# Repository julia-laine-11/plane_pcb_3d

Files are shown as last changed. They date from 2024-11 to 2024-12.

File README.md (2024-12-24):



top view (smt leds & resistors and thru hole resistor holes)



side view (no electronics here)



I ordered them 12/8/24 and they were shipped 12/12/24

They arrived 12/23/24 (very fast!)



I began by adding all the thru hole components on the bottom side of the horizontal piece. The bottom LEDs face forward. Afterwards, I added the surface mount LEDs on the back. I forgot that I didn't have any green 0603s, so I (safely) stole some from a nearby battery pack that was no longer in use. Unfortunately, I lost all but 1 from the very windy reflow station at home. 

Honestly, that was okay though since I really only needed 1 for my dad. I figure I'll give the other 4 as random gifts to my aerospace friends or something.





I then tested it of course, because I desperately wanted to see it, and I was also super nervous I put the 0603 LEDs in backwards since they're so tiny.



(I did put the green LED in backwards once, but I flipped it around and it lit up)

To power it, I used CR2032 batteries with a small piece of tin spot welded onto each side




About now, I realized I forgot to add a switch. I had always intended to glue the battery on, but I'm not sure why I never thought of the switch. 

To power it on I attached small wires onto a potentiometer between the battery + and the PCB. After gluing both the battery and the pot on, I realized that was not going to work since the red SMT LED was always on. 

WhatsAppVideo2024-12-23at20 40 40-ezgif com-crop

I went and found a button and replaced the pot.





It isn't ideal or the prettiest, but it is hidden on the bottom :)

WhatsAppVideo2024-12-23at20 40 21-ezgif com-optimize (1)

I am happy with these results, but there's definitely room for improvement. If I manufacture these again I will definitely add a switch. I also might consider making the slits on each piece a tiny bit wider since there was some minor sanding I had to do. I am not sure if I would do this or not because the pieces fit so nicely after I gently tapped them together with a harder object.

I will also definitely increase the distance of the resistor holes. They were the right size and hold the resistors, but it was a little annoying to bend the wires nicely for them to fit. If the holes were slightly farther apart, they would fit so much better.

I did like how the + and - were on either side of the vertical piece. It made it easier to put the battery in place and not worry about covering up a port. It also let me place a button in and keep the wires relatively short. I would add a small hole or indent for the wire in the future though if I do keep the + on the opposite side. I can also just add a + and - to both sides so I can decide what to do depending on my materials. The school typically has everything I need, but if I am at home I might not have everything.

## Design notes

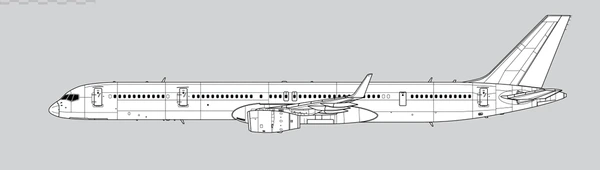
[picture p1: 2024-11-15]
pcb_shape/side reference.webp

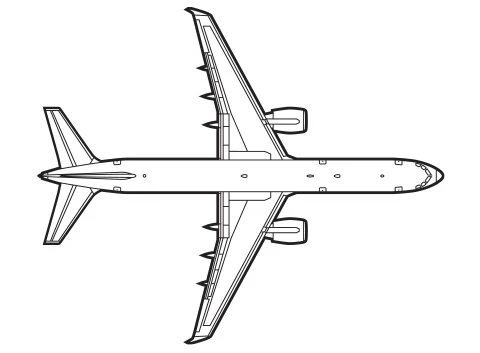
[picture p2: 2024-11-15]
pcb_shape/top reference.webp

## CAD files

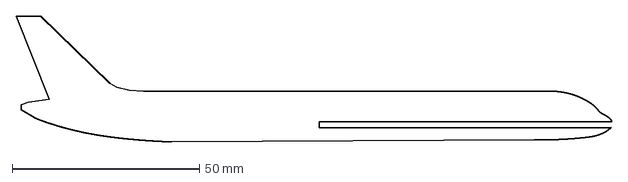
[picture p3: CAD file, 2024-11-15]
pcb_shape/plane side.dxf
159.0 x 33.6 mm

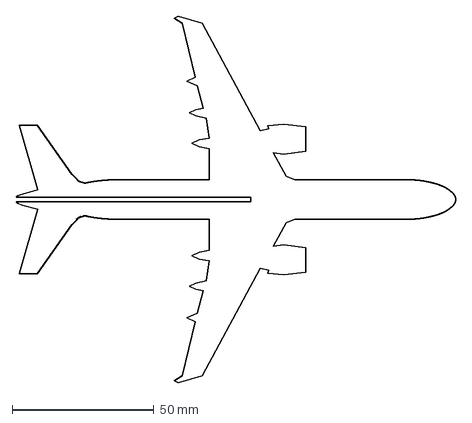
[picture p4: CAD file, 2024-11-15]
pcb_shape/plane top.dxf
155.1 x 129.4 mm

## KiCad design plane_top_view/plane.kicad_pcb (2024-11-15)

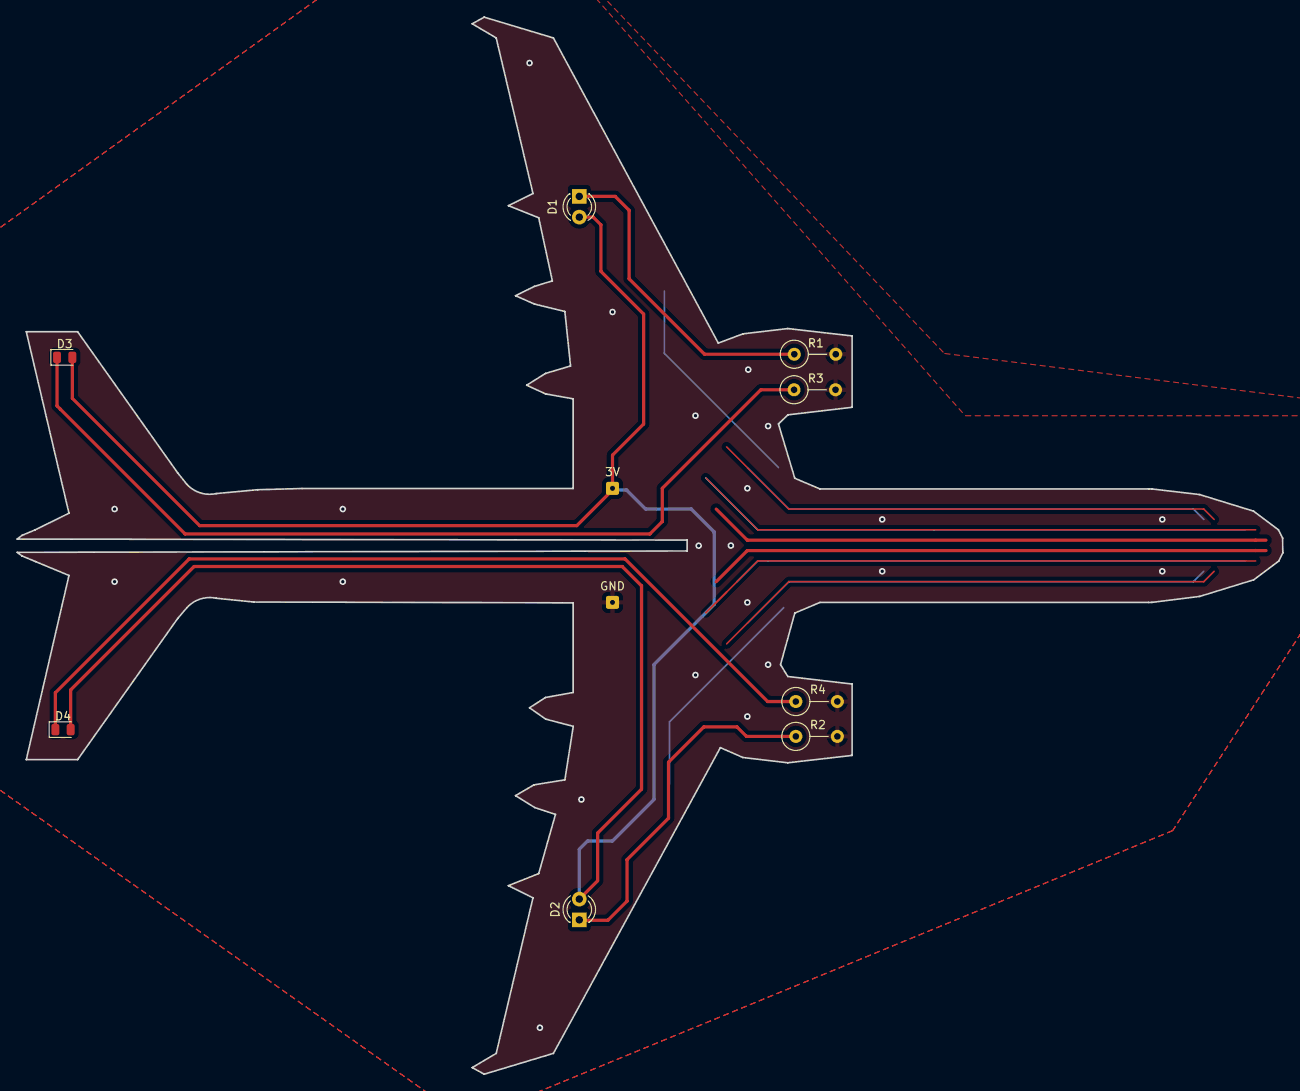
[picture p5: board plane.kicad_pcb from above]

Board: 2 copper layers, 155.0 x 129.4 mm, 10 parts (0 on the bottom side), 6 nets.

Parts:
3V: 3v; SolderWire-0.1sqmm_1x01_D0.4mm_OD1mm
D1, D2: TSAL4400; LED_D3.0mm_IRBlack
D3, D4: LED; LED_0805_2012Metric
GND: GND; SolderWire-0.1sqmm_1x01_D0.4mm_OD1mm
R1, R2, R3, R4: RC0201FR-0710KL; R_Axial_DIN0309_L9.0mm_D3.2mm_P5.08mm_Vertical

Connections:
+3V0: 3V.1, D1.2 (A), D2.2 (A), D3.2 (A), D4.2 (A)
GND: GND.1, R1.2, R2.2, R3.2, R4.2
unnamed: D1.1 (K), R1.1
unnamed: D2.1 (K), R2.1
unnamed: D3.1 (K), R3.1
unnamed: D4.1 (K), R4.1

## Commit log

2024-11-15 uploaded plane kicad project
    [plane-B_Cu.gbr, plane-B_Mask.gbr, plane-B_Paste.gbr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]
2024-11-15 organized into folders
    [plane side.dxf, plane top.dxf]
2024-11-15 changed folders
    [plane-B_Cu.gbr, plane-B_Mask.gbr, plane-B_Paste.gbr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]
2024-11-15 made it less jank
    [plane.kicad_pcb, plane.kicad_sch]
2024-11-15 made it actually have connected grounds
    [plane-B_Cu.gbl, plane-B_Mask.gbr, plane-B_Mask.gbs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]
2024-11-15 fixed my many mistakes
    for some reason I got locked out of the file. so i just saved the files again and then moved them to the repo
    [plane.kicad_pcb, plane.kicad_sch]
2024-11-15 reorganized and verified
    [plane.kicad_pcb, plane.kicad_sch]
2024-11-15 finalized stuff
    [plane_side_view-B_Cu.gbl, plane_side_view-B_Cu.gbr, plane_side_view-B_Mask.gbr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]
2024-12-24 Update README.md since i got the pcbs!
